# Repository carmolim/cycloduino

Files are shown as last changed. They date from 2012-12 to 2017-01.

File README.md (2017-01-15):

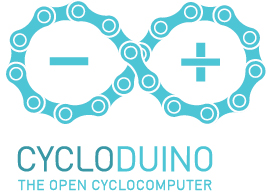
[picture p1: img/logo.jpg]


The Cycloduino is a attempt to create a full featured cyclocomputer using an Arduino.  A cyclocomputer or cyclometer is a device mounted on a bicycle that calculates and displays trip information, similar to the instruments in the dashboard of a car. The computer with display, or head unit, usually is attached to the handlebar for easy viewing.

What will this include:

##Speed

 * Current speed - ok
 * Average speed - ok
 * Maximum speed - ok
 * Trip distance - ok
 * Odometer

##Cadence
 
 * Current cadence - ok
 * Average cadence - ok
 * Top cadence - ok 
 * Cadence zones

##Heart rate functions
 
 * Current heart rate 
 * Average heart rate 
 * Maximum heart rate 
 * Heart rate zones

##Temperature functions
 
 * Current temperature - ok 
 * Minimum temperature - ok 
 * Maximum temperature - ok 
 * Average temperature - ok

##Time functions
 
 * Total moving time 
 * Trip moving time - ok 
 * Trip time - ok 
 * Time (12/24 h) 
 * Stopwatch 
 * Countdown timer

##Altitude measurement functions
 
 * Current altitude - ok
 * Ride total ascent

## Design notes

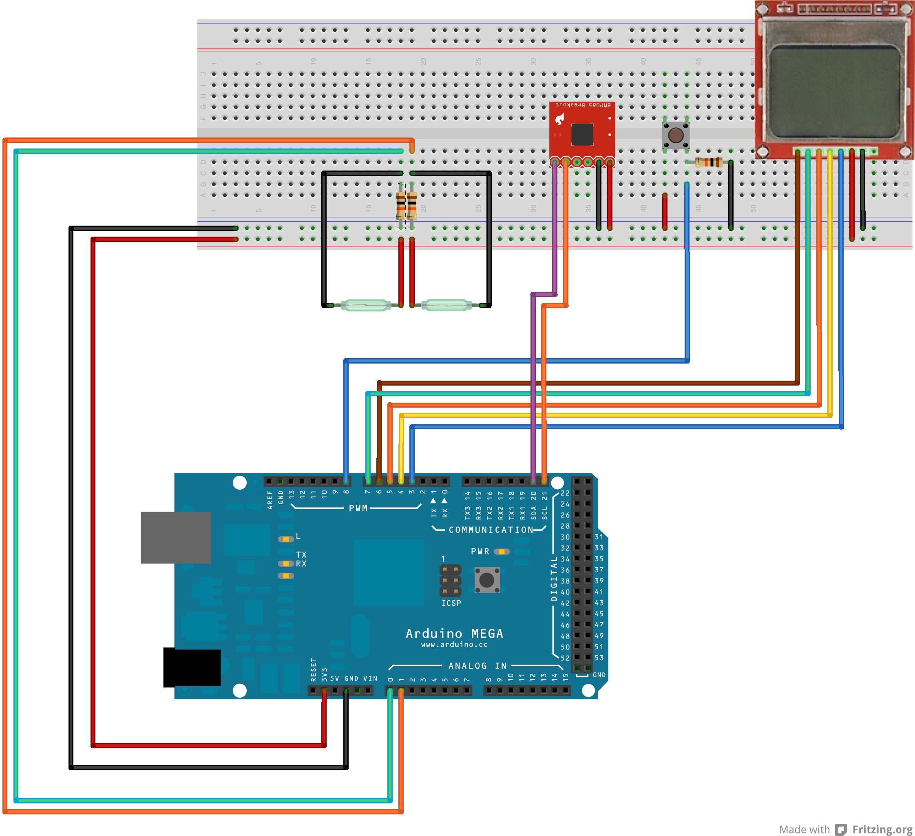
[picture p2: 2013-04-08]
schemev1.0_bb.jpg

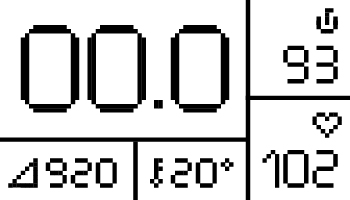
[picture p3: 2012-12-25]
LCD/lcd-07.jpg

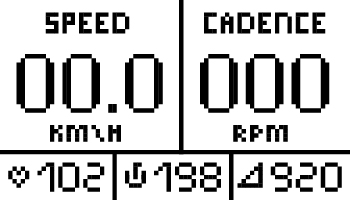
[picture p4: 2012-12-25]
LCD/lcd-08.jpg

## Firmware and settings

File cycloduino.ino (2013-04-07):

// cycloduino - ciclocomputer bike speedometer
// Augusto Carmo (carmolim) 2012 - https://github.com/carmolim/cycloduino
// Inspired on the work of Amanda Ghassae - http://www.instructables.com/id/Arduino-Bike-Speedometer/


/*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
 */


/*
 TODO

 - evitar leituras erradas quando o ima estiver passando com baixa velocidade ou parar na frente do REED
 - porque a leitura da cadência não está fazendo com que inicie a contagem do movingTime?

 
 LOG
 /// 

  - create a file name with date and time - I'll need a DS1302 or DS1307
  - think is going to be easier to just add a sequencial number and make a verification if the file name already exists

 
 SPEED
 /////
 
 OK - current speed
 OK - average speed  
 OK - top speed
 
 
 CADENCE
 ///////
 
 OK - how to calculate cadence
 OK - max cadence
 OK - average cadence
 

 CALORIES
 ////////

 The Journal of Sports Sciences provides a calorie expenditure formula for each gender.

 Men: Calories Burned = ((Age x 0.2017) + (Weight x 0.09036) + (Heart Rate x 0.6309) - 55.0969) x Time / 4.184
 Women: Calories Burned = ((Age x 0.074) -- (Weight x 0.05741) + (Heart Rate x 0.4472) - 20.4022) x Time / 4.184.

 Read more: http://www.livestrong.com/article/221621-formula-for-calories-burned-during-exercise/#ixzz2HWlKgfgJ


 Male: ((-55.0969 + (0.6309 x HR) + (0.1988 x W) + (0.2017 x A))/4.184) x 60 x T
 Female: ((-20.4022 + (0.4472 x HR) - (0.1263 x W) + (0.074 x A))/4.184) x 60 x T
 
 where:
 HR = Heart rate (in beats/minute) 
 W = Weight (in kilograms) 
 A = Age (in years) 
 T = Exercise duration time (in hours)

 other ref: http://www.shapesense.com/fitness-exercise/calculators/heart-rate-based-calorie-burn-calculator.aspx


 HEART RATE
 //////////

 Equation for Determination of Maximum Heart Rate Based on Age
 Maximum Heart Rate (beats/minute) = 208 - (0.7 x age)


 */


// LIBRARIES
////////////
#include <Adafruit_BMP085.h>                    // Barometer
#include <Adafruit_GFX.h>                       // LCD graphics
#include <Adafruit_PCD8544.h>                   // LCD
#include <Wire.h>
//#include <SD.h>


// INTERFACE
////////////

// pin 7 - Serial clock out (SCLK)
// pin 6 - Serial data out (DIN)
// pin 5 - Data/Command select (D/C)
// pin 4 - LCD chip select (CS)
// pin 3 - LCD reset (RST)

Adafruit_PCD8544 display = Adafruit_PCD8544(3, 4, 5, 7, 6);

const int buttonPin        = 8;               // the number of the pushbutton pin
const int ledPin           = 13;              // the number of the LED pin
const int graphSteps       = 42;              // number of lines used for build the graph
int screen                 = 8;               // variable for reading the pushbutton status
int buttonState            = 0;               // variable for reading the pushbutton status
int graphPosition          = 0;               // stores the actual position in the array
int speedGraph[graphSteps];                   // stores the last 42 speed reads to draw the speed graphic


//CYCLES
////////

const int oneSecCycle      = 1000;            // 1 second
unsigned long before1Sec   = 0; 

const int buttonDebounce   = 200;             // 500 milisegundos
unsigned long beforeButton = 0; 


// SENSORS
//////////

const int speedReed        = A0;              // speed reed switch
const int cadenceReed      = A1;              // cadence reed switch


// BAROMETER
////////////

Adafruit_BMP085 bmp;                         // create a barometer object
const int altSamplesAmount = 50;              // number of samples to make the altSamples
int altSamplesStep         = 0;
float altSamples[altSamplesAmount];          // stores the last readings
float averageAltitude      = 0.0;
float altitude             = 0.0;              // stores the actual altitude in meters
float lastAltitude         = 0.0;              // stores the last altitude value
float totalAscent          = 0.0;              // sum of all ascents
float maxAltitude          = 0.0;              // higher altitude in the ride
float minAltitude          = 900.0;            // lowest altitude in the ride
const int filterAltitude   = 1;              // diference between altitude and last altitude
 int altCalibration   = 101490;         // 


// LOG
//////

//File myFile;                                  // object to handle with the file in the SD
String logLine;                               // stores each log line before it is recorded in th SD
char logName[]            = "RIDE_00.csv";    // create an array that contains the name of our file.


// USER INFO
////////////

const int age              = 24;               // age in years of the user
float weight               = 77.5;             // weight in Kg


// HEART RATE
/////////////

float heartRate           = 0.00;             // current bpm
float avgHeartRate        = 0.00;             // average bpm
float maxHeartRate        = 0.00;             // max bpm
float minHeartRate        = 0.00;             // min bpm


// CALORIES
///////////

float caloriesBurned      = 0.00;             // total calories burned


// TOTAL MEASURES
/////////////////

const int maxReedCounter  = 80;               // min time (in ms) of one rotation (for debouncing)
float odometer            = 0;                // total distante
int loopCounter           = 0;                // how many times the loop run before the ride started


// PER RIDE
///////////

long rideTime             = 0;                // total time of the ride
long movingTime           = 0;                // only the moving time
long millisCount          = 0;                // stores the number of cicles runned in the interrupt
float rideDistance        = 0.00;             // total distance of the ride in Km
boolean rideStarted       = false;            // if the bike is moving = true
boolean moving            = false;            // if the bike is moving = true


// SPEED VARIBALES
//////////////////

long speedTimer           = 0;                 // time between one full rotation (in ms)
long speedNumberSamples   = 0;                 // total of revolutions made by the front wheel
float speedSamplesSum     = 0.00;              // sum of all the speeds collected
float circumference       = 210.0;             // lenght of the wheel
float kph                 = 0.00;              // speed in kph
float mph                 = 0.00;              // speed in mph
float topSpeed            = 0.00;              // top speed of the ride
float avgSpeed            = 0.00;              // average speed of the ride
int speedReedVal          = 0;                 // ?? stores if the switch is open or closed // change to boolean?
int speedReedCounter      = 0;                 // ??


// CADENCE VARIABLES
////////////////////

long cadenceTimer         = 0;                 // time between one full rotation (in ms)
long cadenceNumberSamples = 0;                 // total of revolutions made by the front wheel
float cadenceSamplesSum   = 0.00;              // sum of all the speeds collected
float cadence             = 0.00;              // actual cadence
float avgCadence          = 0.00;              // average cadence of the ride
float topCadence          = 0.00;              // top cadence fo the ride
int cadenceReedVal        = 0;                 // stores if the switch is open or closed // change to boolean?
int cadenceReedCounter    = 0;                 // ??


// TEMPERATURE
//////////////

float temperature        = 0.00;               // stores the temperature
float maxTemp            = 0.00;               // stores the maximum temperature of the ride
float minTemp            = 100.00;             // stores the minimum temperature of the ride
float avgTemp            = 0.00;               // stores the average temp of the ride
float tempSum            = 0.00;               // sum of all the temperature reads


//////////////////////////////////////////////////////////////////////////////////////////////////////
//////////////////////////////////////////////////////////////////////////////////////////////////////

// SETUP

//////////////////////////////////////////////////////////////////////////////////////////////////////
//////////////////////////////////////////////////////////////////////////////////////////////////////


void setup()
{

  // BAROMETER

  // initializate the BMP085
  if (!bmp.begin())
  {
   Serial.println("Could not find a valid BMP085 sensor, check wiring!");
   while (1) {}
  }
  

  for (int i = 0; i < altSamplesAmount; i++)
  {
    altSamples[i] = bmp.readAltitude(101490); 
  }

  minAltitude = bmp.readAltitude(101490);       // initiates withe the actual altitude
  lastAltitude = bmp.readAltitude(101490);      // initiates withe the actual altitude
  
  

  speedReedCounter = maxReedCounter;      // ?
  cadenceReedCounter = maxReedCounter;    // ?


  // On the Ethernet Shield, CS is pin 4. It's set as an output by default.
  // Note that even if it's not used as the CS pin, the hardware SS pin 
  // (10 on most Arduino boards, 53 on the Mega) must be left as an output 
  // or the SD library functions will not work. 

  // speed input
  pinMode(speedReed, INPUT);

  // cadence input                   
  pinMode(cadenceReed, INPUT); 

  // pushbutton input:
  pinMode(buttonPin, INPUT);   

  // LCD

  // init done
  display.begin();   

  // you can change the contrast around to adapt the display
  // for the best viewing!
  display.setContrast(50);


  // iniciates the array
  for (int i = 0; i < graphSteps; i++)
  {      
    speedGraph[i] = 0;     
  }


  // SD
  
  /*

  if (!SD.begin(4))
  {
    Serial.println("initialization failed!");
    return;
  }

  Serial.println("initialization done."); 
  */
/*
  TODO

  1 - search if there is a filename that starts with 01
  2 - if it finds a filename that starts with 01, find if there is a filename that starts with 02,03,04...
  3 - after find the last log add 1 to logCount and start a new log with this number

  REF
  http://arduino.cc/forum/index.php?topic=108264.0
  http://arduino.cc/forum/index.php?PHPSESSID=a96c1ff6fa88ecd4d0d0094696a1edeb&/topic,105997.0.html
  * - http://www.ladyada.net/make/logshield/lighttempwalkthru.html

  TEST
*/

/*
  // while the filename exists...
  while(SD.exists(logName))
  { 
    logCount += 1;                 // adds 1 to the counter
    logName[5] = logCount / 10 + '0';
    logName[6] = logCount % 10 + '0';
  }   

  // open the file. note that only one file can be open at a time,
  // so you have to close this one before opening another.
  myFile = SD.open(logName, FILE_WRITE);  
*/


/*
  // create a new file
  for (uint8_t i = 0; i < 100; i++)
  {
    logName[5] = i/10 + '0';
    logName[6] = i%10 + '0';
    if (!SD.exists(logName))
    {
      // only open a new file if it doesn't exist
      myFile = SD.open(logName, FILE_WRITE); 
      break;  // leave the loop!
    }
  }


  // if the file opened okay, write to it
  if (myFile)
  {
    //Serial.print("Writing to log...");
    myFile.print("speed; avgSpeed; rotations S; cadence; avgCadence; rotations C; rideTime; movingTime; temperature;");
    myFile.println();

    // close the file:
    myFile.close();   
  }   */

  // WEIGHT

  // convert Kg to Lbs
  weight = weight * 2.20462262184877580723; 

 
  // TIMER SETUP - the timer interrupt allows precise timed measurements of the reed switch
  // for more info about configuration of arduino timers see http://arduino.cc/playground/Code/Timer1

  cli(); // stop interrupts

  // set timer1 interrupt at 1kHz
  TCCR1A = 0; // set entire TCCR1A register to 0
  TCCR1B = 0; // same for TCCR1B
  TCNT1  = 0;

  // set timer count for 1khz increments
  OCR1A = 1999; // = (1/1000) / ((1/(16*10^6))*8) - 1

  // turn on CTC mode
  TCCR1B |= (1 << WGM12);

  // Set CS11 bit for 8 prescaler
  TCCR1B |= (1 << CS11); 

  // enable timer compare interrupt
  TIMSK1 |= (1 << OCIE1A);

  sei(); //allow interrupts

  //END TIMER SETUP

  Serial.begin(9600);

}// setup end


//////////////////////////////////////////////////////////////////////////////////////////////////////
//////////////////////////////////////////////////////////////////////////////////////////////////////

// TIMER

//////////////////////////////////////////////////////////////////////////////////////////////////////
//////////////////////////////////////////////////////////////////////////////////////////////////////


// Interrupt at freq of 1000 Hz to measure reed switch
ISR(TIMER1_COMPA_vect)
{

  //SPEED
  ///////

  // get val of A0
  speedReedVal = digitalRead(speedReed);

  // if reed switch is closed
  if (speedReedVal)
  {
    //min time between pulses has passed
    if (speedReedCounter == 0)
    {
      // min time between pulses has passed
      kph = (36*float(circumference))/float(speedTimer); // calculate kilometers per hour
  
      // reset speedTimer      
      speedTimer = 0;

      // reset speedReedCounter
      speedReedCounter = maxReedCounter;

      // increase number of samples by 1 - number of wheel rotations ajust the debouncer??
      speedNumberSamples++;  

      // starts the chronometer
      rideStarted = true;

      // the wheel is spinning
      moving = true;
    }

    else
    {
      if (speedReedCounter > 0)
      {
        // don't let speedReedCounter go negative
        speedReedCounter -= 1; // decrement speedReedCounter
      }
    }
  }

  else
  {
    // if reed switch is open
    if (speedReedCounter > 0)
    {
      // don't let speedReedCounter go negative
      speedReedCounter -= 1; // decrement speedReedCounter
    }
  }

  if (speedTimer > 2000)
  {
    // if no new pulses from reed switch- tire is still, set kmh to 0
    kph = 0; 

    // the bike is not moving
    moving = false;
  }

  else
  {
    speedTimer += 1; // increment speedTimer
  } 


  // CADENCE
  //////////

  // get val of A1
  cadenceReedVal = digitalRead(cadenceReed);

  // if reed switch is if closed
  if(cadenceReedVal)
  {
    //min time between pulses has passed
    if (cadenceReedCounter == 0)
    {
      // calculate rotations per minute 
      cadence = float(60000)/float(cadenceTimer);

      // reset timer
      cadenceTimer = 0;

      // reset reedCounter
      cadenceReedCounter = maxReedCounter;

      // increase number of samples by 1      
      cadenceNumberSamples++;  

      // starts the chronometer
      rideStarted = true;

      // the wheel is spinning
      moving = true;                                 
    }

    else
    {
      if(cadenceReedCounter > 0)
      {// don't let cadenceReedCounter go negative

        // decrement cadenceReedCounter
        cadenceReedCounter -= 1;    
      }
    }
  }

  // if reed switch is open
  else
  {
    // don't let cadenceReedCounter go negative
    if (cadenceReedCounter > 0)
    {   
      // decrement cadenceReedCounter
      cadenceReedCounter -= 1;
    }
  }

  if (cadenceTimer > 2000)
  {
    cadence = 0; 
  }

  else
  {
    cadenceTimer += 1; // increment timer
  } 


  // TIME
  ///////

  // if the timeCount is == to 1000 (1s)
  if(millisCount == 1000)
  {
    // if the ride started...
    if(rideStarted)
    {
      // increments 1 once a second
      rideTime += 1;  
    }
    
    // if the bike is moving...
    if(moving)
    {
      // increments 1 once a second
      movingTime += 1;
    }
    
    // reset the counter
    millisCount = 0; 
  }

  // increments 1 every cicle
  millisCount += 1;

} // end of timer


//////////////////////////////////////////////////////////////////////////////////////////////////////
//////////////////////////////////////////////////////////////////////////////////////////////////////

// LOOP

//////////////////////////////////////////////////////////////////////////////////////////////////////
//////////////////////////////////////////////////////////////////////////////////////////////////////
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

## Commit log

2012-11-24 General Ajusts
    Nothing new… improving the code organization...
2012-11-26 Temp sensor, speed ajusts, and time method
    Add the codes for the temperature readings, maxTemp, minTemp, avgTemp,
    tempSum, temperature.
    Change the speedSamplesSum and the cadenceSamplesSum to float. Now the
    averages are correct.
    New method to output time in 0:0:0 format
    [cycloduino.ino]
2012-12-06 Move some code out of the interrupt code...
    Move some calculations to loop() to let less code in the interrupt timer.
2012-12-07 More precise time count
    Move the time count to the timer to get more precise measures.
2013-01-09 Better code
    Change some variables to cont
    Add the to do list for calories calculation
    Delete a variable that was not being used
    Code clean up
    -- not tested in the arduino
2013-01-10 Calories variables and calculation
    Add the calories variables
    Add the heart rate variables
    Add the calories burned calculation
    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
    [cycloduino.ino]
2013-01-10 Correction in the calories burned calculation
    [cycloduino.ino]
2013-01-27 Add suport to LCD 5110
    Add the basic code to display variables in the LCD Nokia 5110. Need to
    repair the variables display.
    -- test ok
    [scheme.fzz]
2013-01-27 Change the LCD Library to Adafruit + pushbutton
    Change th LCD library to the Adafruit, to get bigger fonts, and more
    resources, now the push button change the page in the LCD screen, but I
    need to debounce the signal, I thing the best solution is a hardware
    debounce, but I don't have the itens to test.
2013-01-27 New page, top speed fixed.
    Log recor activate
    New LCD page - Summary
    LCD starts at page 6 - Summary
    Decrease the maxReedCounter to get a bigger top speed.
    [scheme.fzz, scheme2.fzz]
2013-02-06 New screen model: bar chart with the speed. Remove the delay at the end of the loop to make the button debounce work. Added inside the loop a conditional thtat executes the code inside second by seco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
2013-03-06 My ethernet shield with micro SD, stopped working, to proceed I comment all the lines that involved the log and the SD, now everthing is working again.
    My BMP085 arrived, now I'm getting the temperature and the altitude
    reading from it, no mor need for the DS18B20.
    Add the code to calculate the total ascent and total descent don't know
    if that is working yet, will do some tests.
    tested in arduino!
2013-03-06 Some ajusts
    Made some ajusts to the ascent calculations, but is not working
    correctly, I'll have to make a lot of tests to make this work, and is
    goi to be difficult becouse you can not simulate air pressure easey.
    Some sugestion?
    [cycloduino.ino]
2013-04-08 Circuit schema
    [schemev1.0.fzz]

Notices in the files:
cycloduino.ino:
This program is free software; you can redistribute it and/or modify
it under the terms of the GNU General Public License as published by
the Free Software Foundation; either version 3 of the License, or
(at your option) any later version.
